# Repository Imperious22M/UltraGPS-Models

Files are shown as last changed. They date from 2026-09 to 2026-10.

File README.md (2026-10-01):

# UltraGPS Models

3D-printable hardware for the St. Mary's University **UltraGPS** indoor
positioning system, developed as part of graduate and undergraduate research.

## What is here

SolidWorks sources and STL exports for every printed part of the system:

| Directory | Contents |
|---|---|
| `Transmitter-Models/` | Transmitter tower sections and transducer holders |
| `Receiver-Arena-Models/Solidwork/Receiver-Parts/` | Receiver tower parts and arena parts |
| `Receiver-Arena-Models/Solidwork/PVC-Arena-Base-Parts/` | PVC-pipe arena base extenders and PCB holder (no STL exports yet) |
| `docs/` | The documentation site (MkDocs) |

Each subsystem is mirrored as `Solidwork/` (`.SLDPRT` / `.SLDASM` / `.SLDDRW`)
and `STL/`. Every SolidWorks part that has an STL export shares its basename with it.

These parts are the physical side of the system whose software lives in
[UltraGPS-Arduino](https://github.com/Imperious22M/UltraGPS-Arduino) (firmware),
[UltraGPS-Ground](https://github.com/Imperious22M/UltraGPS-Ground) (ground station)
and [UltraGPS-Control](https://github.com/Imperious22M/UltraGPS-Control)
(operator GUI).

## Documentation

The MKDocs documentation can be found [here](https://imperious22m.github.io/UltraGPS-Models).

- **Home** — what is in the repository and how it is laid out.
- **Receiver Assembly** — building a receiver tower.
- **Transmitter Assembly** — building the transmitter tower and the
  transducer holder.
- **PVC Arena Assembly** — using the printed adapters that join a receiver
  tower to the PVC pipe frame.

### Previewing the docs locally

`build.sh` is the docs entry point, mirroring the software repositories.

```bash
pip install -r docs/requirements.txt
./build.sh docs         # live preview at http://127.0.0.1:8000
./build.sh docs-build   # render into ./site/
./build.sh clean        # remove ./site/
```

### Publishing Flow

Pushing a change to `docs/`, to `mkdocs.yml`, or to the `release` branch runs 
`.github/workflows/docs.yml`, which builds the site and pushes it to the `gh-pages` 
branch that GitHub Pages serves. The workflow can also be run by hand from the Actions 
tab.

## Working with the CAD files

- SolidWorks files are binary; only SolidWorks can edit them. The STLs are what
  you print.
- SolidWorks files can be edited only in SolidWorks.

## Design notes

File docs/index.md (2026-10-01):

# UltraGPS Models

3D-printable models for the St. Mary's University **UltraGPS** indoor
positioning system, developed as part of graduate research.

This repository holds the SolidWorks sources and STL exports for every printed
part in the system. In each major folder of the repository, the **Solidworks** 
folder holds all of the solidworks models and the **STL** folder holds all of the
printables STL files.

In **Receiver-Arena-Models** you can find the components that interface between PVC pipes and the receiver components as well as the components that make up the receiver tower.

In **Transmitter-Models** you can find the components that make the example transmitter tower.

## Documentation

- **[Receiver Assembly](receiver-assembly.md)** — building a receiver tower.
- **[Transmitter Assembly](transmitter-assembly.md)** — building the transmitter tower,
  and the transducer holder.
- **[PVC Arena Assembly](pvc-arena-assembly.md)** — using the printed adapters
  that join a receiver tower to the PVC pipe frame.

## Repository layout

```
Transmitter-Models/
  Solidwork/   Solidwork parts
  STL/         Tower sections and transducer holders
Receiver-Arena-Models/
  Solidwork/
    Receiver-Parts/          Receiver tower parts + assemblies
    PVC-Arena-Base-Parts/    PVC-pipe arena base extenders and PCB holder
  STL/
    Receiver-Holder/         Receiver tower exports
    Arena-Base/              (empty — arena base STLs not yet exported)
docs/          This site
```

Every `.SLDPRT` that has an STL export shares its basename with that STL, so
`Transmitter-tower-middle.SLDPRT` is the source of
`Transmitter-tower-middle.STL`.

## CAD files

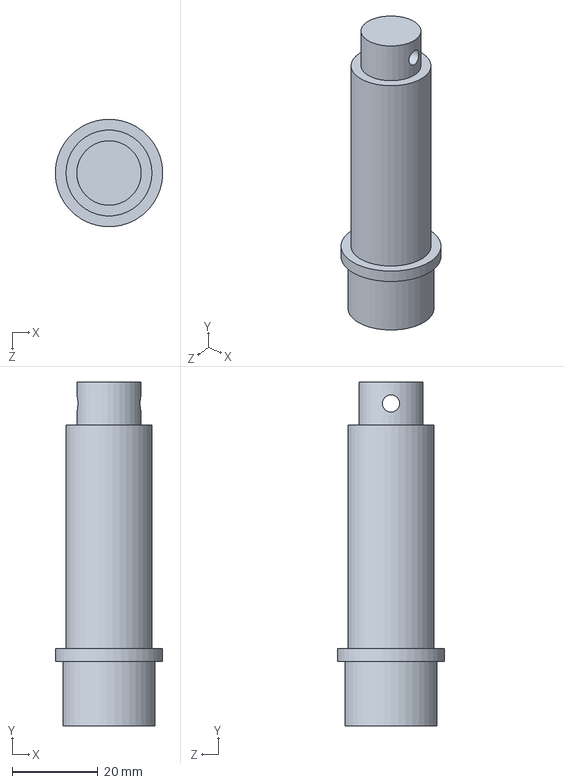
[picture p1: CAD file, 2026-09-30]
Receiver-Arena-Models/Solidwork/PVC-Arena-Base-Parts/standExtenderPVCBase.SLDPRT
25.0 x 80.0 x 24.9 mm

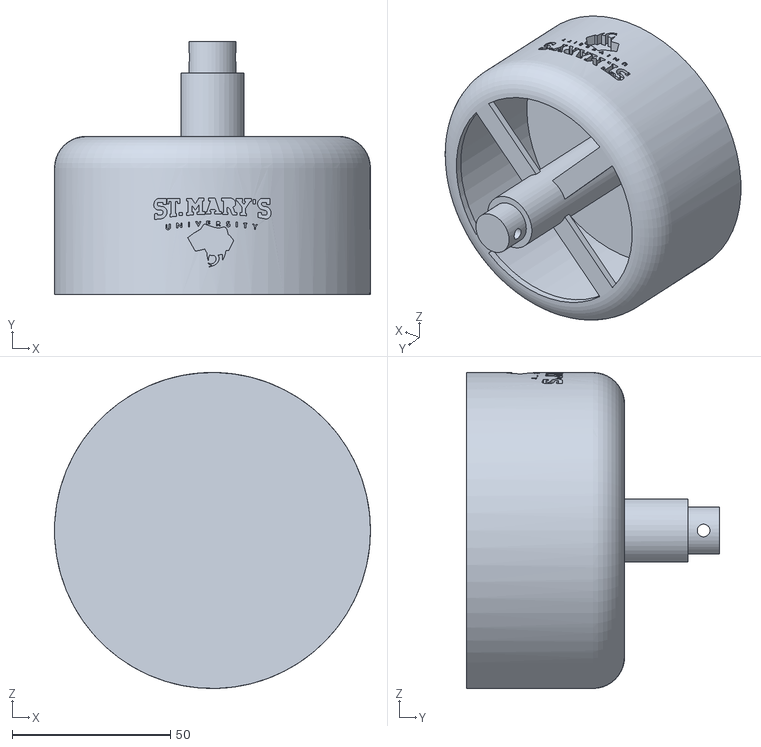
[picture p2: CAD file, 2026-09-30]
Receiver-Arena-Models/STL/Receiver-Holder/Receiver-tower-base.STL
100.0 x 80.0 x 100.0

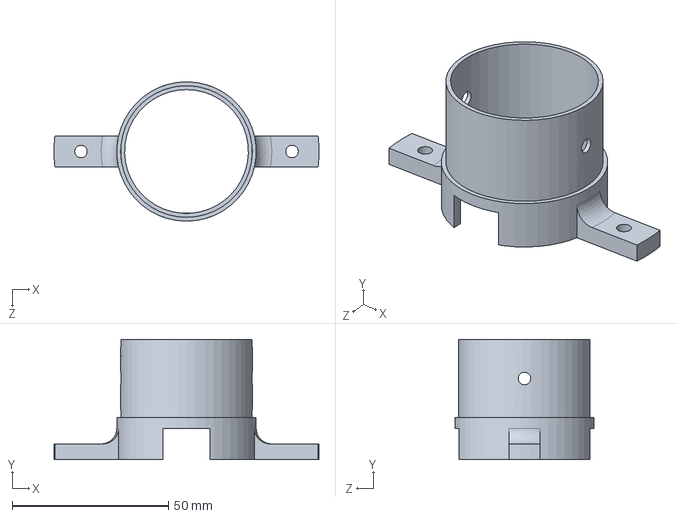
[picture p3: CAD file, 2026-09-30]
Transmitter-Models/Solidwork/Transmitter-tower-base-flared.SLDPRT
84.7 x 38.4 x 44.6 mm

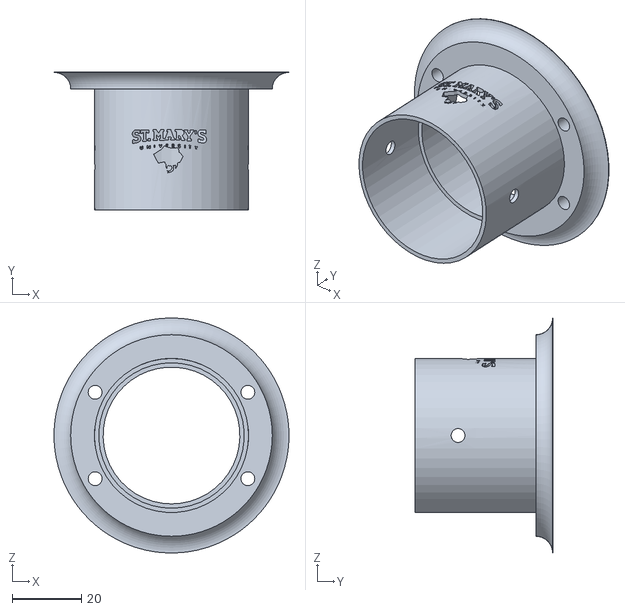
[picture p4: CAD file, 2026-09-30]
Transmitter-Models/STL/Transmitter-tower-top-attachment.STL
68.0 x 40.0 x 68.0

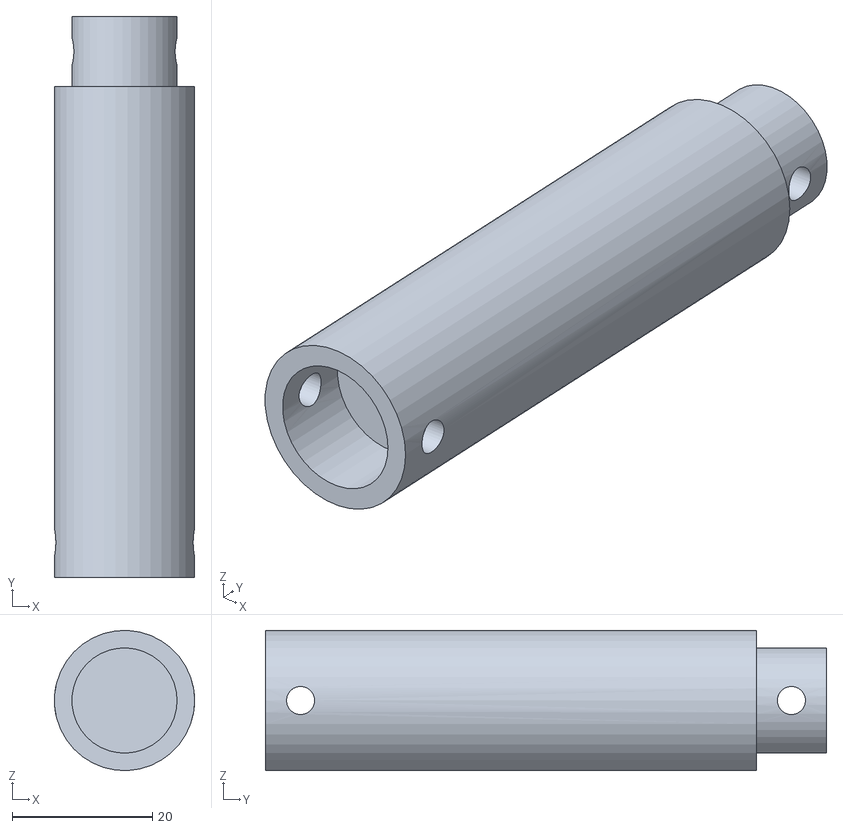
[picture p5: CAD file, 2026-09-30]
Receiver-Arena-Models/STL/Receiver-Holder/Receiver-tower-middle-connector.STL
20.0 x 80.0 x 20.0

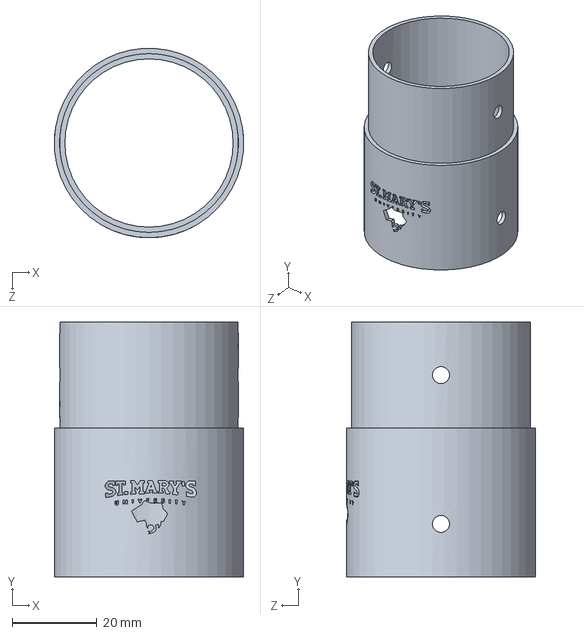
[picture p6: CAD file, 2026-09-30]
Transmitter-Models/Solidwork/Transmitter-tower-middle.SLDPRT
44.6 x 60.0 x 44.6 mm

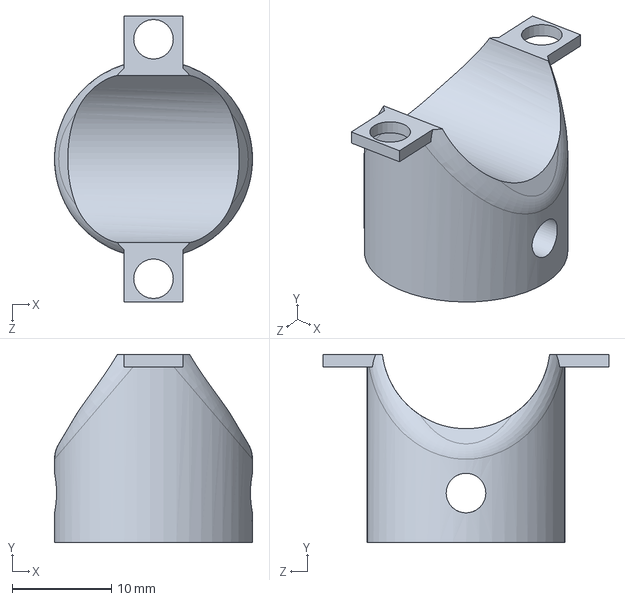
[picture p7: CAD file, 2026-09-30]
Receiver-Arena-Models/Solidwork/Receiver-Parts/Transmitter-holder-single-bottom.SLDPRT
20.0 x 19.0 x 28.9 mm

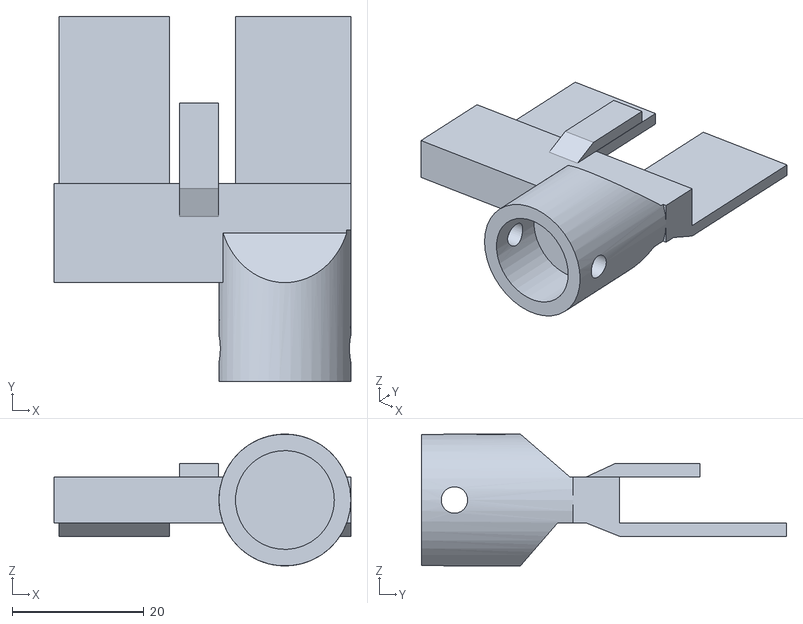
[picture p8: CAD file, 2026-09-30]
Receiver-Arena-Models/STL/Receiver-Holder/Receiver-tower-top-ultrasonic-holder.STL
45.0 x 55.4 x 20.0

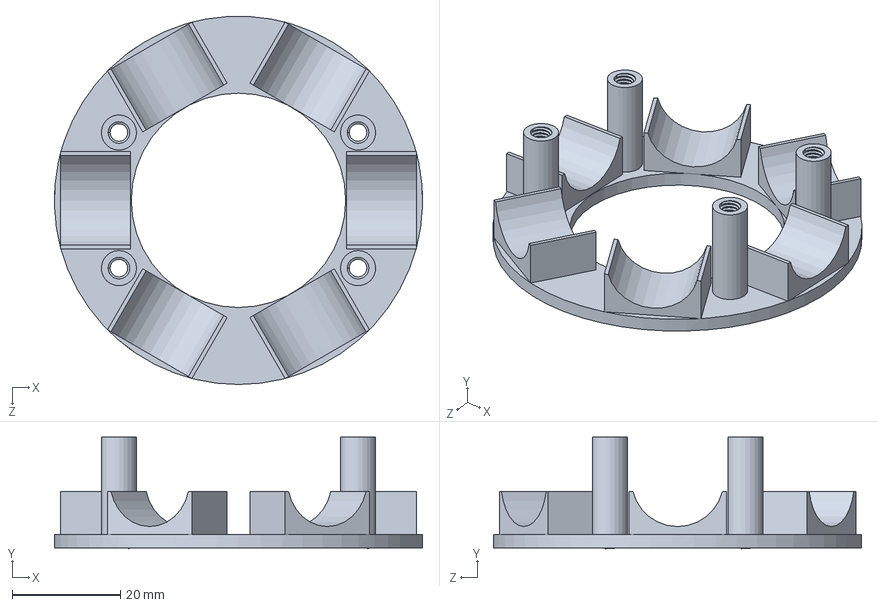
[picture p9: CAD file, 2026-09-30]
Transmitter-Models/Solidwork/Transmitter-holder-multi-top.SLDPRT
68.0 x 20.6 x 67.9 mm

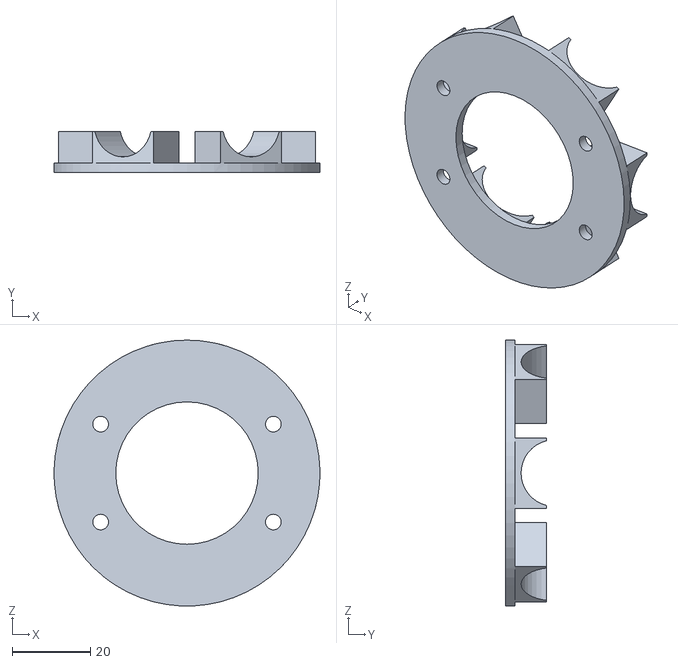
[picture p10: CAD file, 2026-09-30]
Transmitter-Models/STL/Transmitter-holder-multi-bottom.STL
68.0 x 10.5 x 68.0

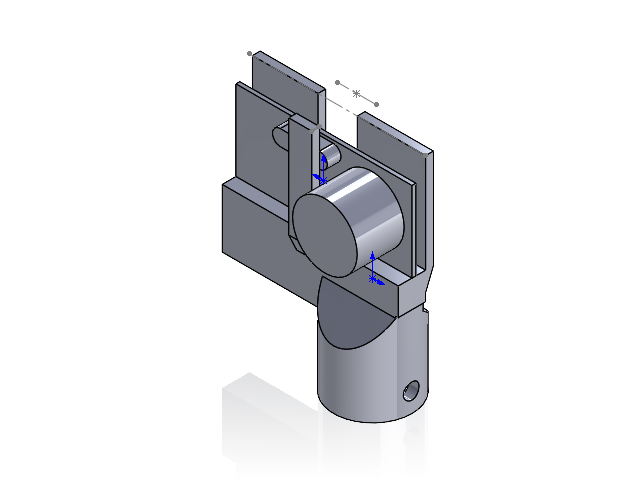
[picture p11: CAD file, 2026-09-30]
Receiver-Arena-Models/Solidwork/Receiver-Parts/receiverwithboardholder.SLDASM
ReceiverWBoardHolder
ReceiverWboard

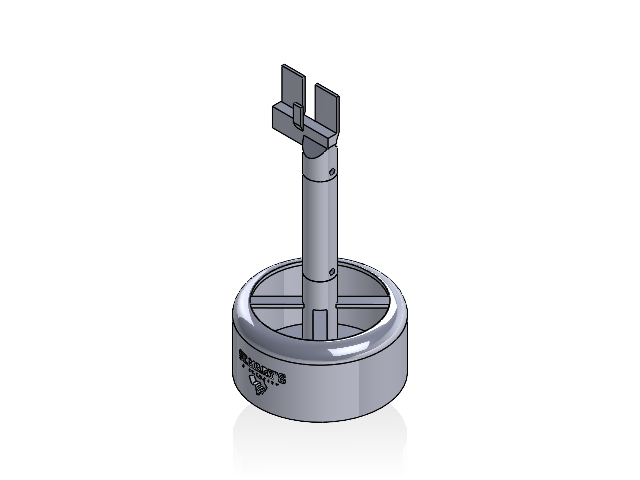
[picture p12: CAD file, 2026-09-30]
Receiver-Arena-Models/Solidwork/Receiver-Parts/ReceiverAssem.SLDASM
Base
standExtender
ReceiverWBoardHolder

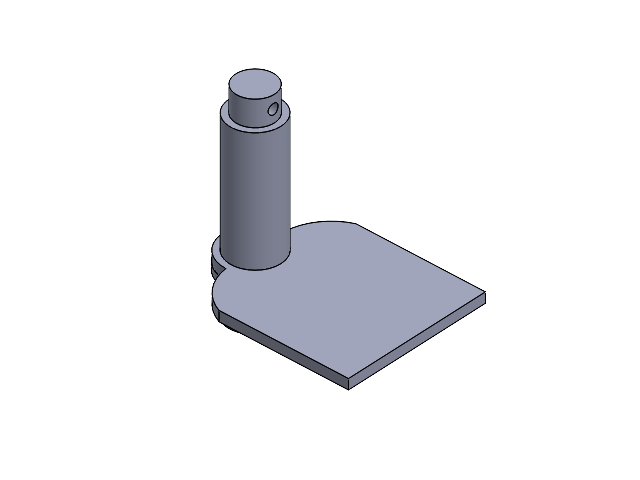
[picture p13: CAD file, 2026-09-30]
Receiver-Arena-Models/Solidwork/PVC-Arena-Base-Parts/PVC Holder Assm.SLDASM
standExtenderPVCBase
circuitBoardHolder

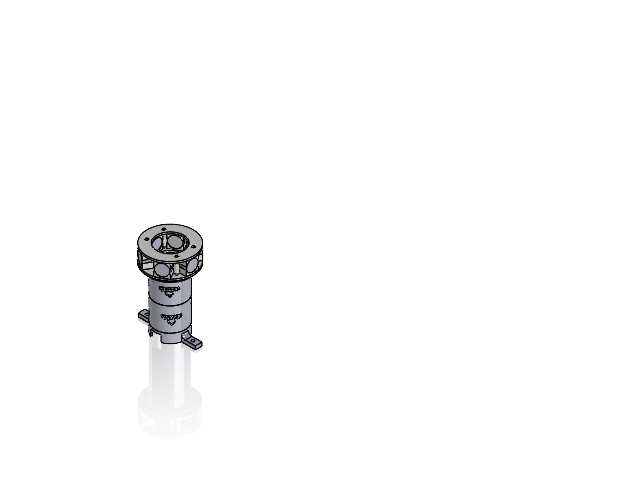
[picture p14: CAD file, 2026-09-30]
Transmitter-Models/Solidwork/Transmitter Assembly.SLDASM
Transmitter HolderTop
Transmitter Holder
transceiver x 6
Transmitter base attachment
Transmitter attachment middle
Transmitter attachment base2

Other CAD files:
Receiver-Arena-Models/Solidwork/PVC-Arena-Base-Parts/standExtenderPVCBaseWithPCBHolder.SLDPRT
Transmitter-Models/STL/Transmitter-tower-base-flared.STL
Receiver-Arena-Models/Solidwork/PVC-Arena-Base-Parts/circuitBoardHolder.SLDPRT
Receiver-Arena-Models/Solidwork/Receiver-Parts/Receiver-tower-base.SLDPRT
Receiver-Arena-Models/Solidwork/Receiver-Parts/Receiver-tower-middle-connector.SLDPRT
Receiver-Arena-Models/Solidwork/Receiver-Parts/Receiver-tower-top-ultrasonic-holder.SLDPRT
Receiver-Arena-Models/Solidwork/Receiver-Parts/ReceiverWboard.SLDPRT
Receiver-Arena-Models/Solidwork/Receiver-Parts/Transmitter-holder-single-top.SLDPRT
Transmitter-Models/STL/Transmitter-holder-multi-top.STL
Transmitter-Models/STL/Transmitter-holder-single-bottom.STL
Transmitter-Models/STL/Transmitter-holder-single-top.STL
Transmitter-Models/STL/Transmitter-tower-middle-2.STL
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

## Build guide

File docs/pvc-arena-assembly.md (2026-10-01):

# PVC Arena Assembly

The receiver towers stand on a frame of PVC pipe. The parts on this page are the
printed adapters that join a receiver tower to that pipe. They live in
`Receiver-Arena-Models/Solidwork/PVC-Arena-Base-Parts/`.

!!! warning "No STL exports yet"
    `Receiver-Arena-Models/STL/Arena-Base/` is empty. These parts exist only as
    SolidWorks sources.

## Parts

| Part (SolidWorks) | Role |
|---|---|
| `PVC Holder Assm.SLDASM` | Assembly showing the parts below fitted to a section of PVC pipe |
| `standExtenderPVCBase.SLDPRT` | Adapter that clamps to the pipe and presents a receiver-tower mount on top |
| `standExtenderPVCBaseWithPCBHolder.SLDPRT` | The same adapter with a circuit-board holder built in, for when the receiver's board sits at the pipe rather than up the tower |
| `circuitBoardHolder.SLDPRT` | Stand-alone board holder, for use with the plain adapter |
| `standExtender.SLDPRT` | Plain riser — the same part as the receiver tower's `Receiver-tower-middle-connector` |

Open `PVC Holder Assm.SLDASM` to see how the pieces sit on the pipe; the
assembly is the reference for orientation.

## Choosing an adapter

Each receiver tower needs one adapter. Pick per mounting point:

| If… | Print |
|---|---|
| The receiver board mounts on the tower, away from the pipe | `standExtenderPVCBase` |
| The receiver board should sit at the pipe, under the tower | `standExtenderPVCBaseWithPCBHolder` |
| The board needs its own mount somewhere else on the frame | `standExtenderPVCBase` + `circuitBoardHolder` |

## Fitting

1. **Export and print** the chosen adapter for each mounting point (see the
   warning above).
2. **Seat the adapter on the pipe** at the mounting point, matching the
   orientation in `PVC Holder Assm.SLDASM`, with the tower mount facing up.
3. If using the PCB-holder variant or a separate `circuitBoardHolder`, fit the
   board holder so the board is clear of the tower's footprint.
4. **Seat a receiver tower** on the adapter — see
   [Receiver Assembly](receiver-assembly.md). The tower's base sits on the
   adapter; use one or more `standExtender` / `Receiver-tower-middle-connector`
   risers between them if the receiver needs to sit higher.

Repeat for all six mounting points.

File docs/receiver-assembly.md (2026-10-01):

# Receiver Assembly

A receiver tower raises one receiver off the arena frame and holds it pointed
into the arena. This page covers one tower; the system uses six in it's default configuration.

## Parts

STL exports are in `Receiver-Arena-Models/STL/Receiver-Holder/`; SolidWorks
sources in `Receiver-Arena-Models/Solidwork/Receiver-Parts/`. Sizes are the
STL bounding box in millimetres (X × Y × Z as exported).

| STL | Size (mm) | Role |
|---|---|---|
| `Receiver-tower-base` | 100 × 80 × 100 | Foot of the tower. Seats on the arena frame or a [PVC adapter](pvc-arena-assembly.md). |
| `Receiver-tower-middle-connector` | 20 × 80 × 20 | 80 mm riser between base and top. Stack more than one to raise the receiver. |
| `Receiver-tower-top-ultrasonic-holder` | 45 × 55.4 × 20 | Cradle for the receiver module and its board. |

The SolidWorks assemblies are the reference for how the parts fit:

| Assembly | Contents |
|---|---|
| `ReceiverAssem.SLDASM` | The full tower |
| `receiverwithboardholder.SLDASM` | The receiver and its board (`ReceiverWboard.SLDPRT`) seated in `Receiver-tower-top-ultrasonic-holder` |

## Printing

Print one of each part per tower. They are exported in their intended print
orientation; the base is the tallest at 100 mm. No supports should be needed
for the connector or holder.

## Building a tower

1. Press the **middle connector** into the socket on top of the **base**. Add
   a second connector (or a `standExtender` from the PVC parts — it is the
   same part) if the receiver needs to sit higher.
2. Seat the receiver and its board into the **top holder**, as shown in
   `receiverwithboardholder.SLDASM`.
3. Seat the loaded holder on the top of the connector.
4. Stand the tower on the arena frame — directly, or on a
   [PVC adapter](pvc-arena-assembly.md) — and turn it so the receiver faces the
   centre of the arena.
5. Label the tower with its receiver number (1–6) so it can be matched to its
   position later.

All six towers should end up with the receiver at the same height.

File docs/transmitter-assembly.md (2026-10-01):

# Transmitter Assembly

The transmitter tower carries the ultrasonic transducer that gets tracked. It
is a stack of printed sections with a two-part holder on top that clamps the
transducer.

## Parts

STL exports are in `Transmitter-Models/STL/`; SolidWorks sources, the full
assembly (`Transmitter Assembly.SLDASM`) and its drawing
(`Transmitter Assembly.SLDDRW`) in `Transmitter-Models/Solidwork/`. Sizes are
the STL bounding box in millimetres (X × Y × Z as exported).

### Tower

Bottom to top:

| STL | Size (mm) | Role |
|---|---|---|
| `Transmitter-tower-base-flared` | 84.7 × 38.4 × 44.6 | Flared foot that mounts the tower to whatever is being tracked |
| `Transmitter-tower-middle` | 44.6 × 60 × 44.6 | 60 mm riser section |
| `Transmitter-tower-middle-2` | 44.6 × 35 × 44.6 | 35 mm riser section — combine with the 60 mm one to set the height |
| `Transmitter-tower-top-attachment` | 68 × 40 × 68 | Top of the tower; the transducer holder mounts on this |

### Transducer holders

Two variants, each printed as a top and bottom half that close around the
transducer:

| STL | Size (mm) | Role |
|---|---|---|
| `Transmitter-holder-multi-top` | 68 × 20.6 × 68 | Top half of the 68 mm ring holder for a multi-transducer head |
| `Transmitter-holder-multi-bottom` | 68 × 10.5 × 68 | Bottom half of the same ring |
| `Transmitter-holder-single-top` | 10.5 × 9 × 28.9 | Top half of the clip for a single transducer |
| `Transmitter-holder-single-bottom` | 20 × 19 × 28.9 | Bottom half of the single-transducer clip |

The **multi** holder's 68 mm footprint matches the top attachment; the
**single** holder is a small clip for one transducer. Print the pair for
whichever head you are building. `Transmitter Assembly.SLDASM` shows the
default build.

## Printing

Print the four tower sections (or only the risers you need) and one holder
pair. All are exported in their intended orientation.

## Building the tower

1. Stack **base-flared → middle and/or middle-2 → top-attachment**. Use the
   60 mm riser, the 35 mm riser, or both to bring the transducer to the same
   height as the receivers.
2. Clamp the transducer between the two halves of the holder.
3. Seat the loaded holder on the top attachment.
4. Fix the flared base to the platform being tracked, with the transducer
   facing outwards so it has a clear line to the receivers around the arena.

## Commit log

2026-09-30 Add solidwork files and STL files
    [Base.SLDPRT, PVC Holder Assm.SLDASM, Receiver-tower-base.STL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]
2026-09-30 Rename solidworks parts to match their STL exports
    Renamed 11 SLDPRT files so that they match the STL files
    [Receiver-tower-base.SLDPRT, Receiver-tower-middle-connector.SLDPRT, Receiver-tower-top-ultrasonic-holder.SLDPRT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]
2026-10-01 Add pvc-arena-assembly
